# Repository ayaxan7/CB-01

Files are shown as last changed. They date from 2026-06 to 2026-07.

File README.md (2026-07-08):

# NeonCore

<p align="center">
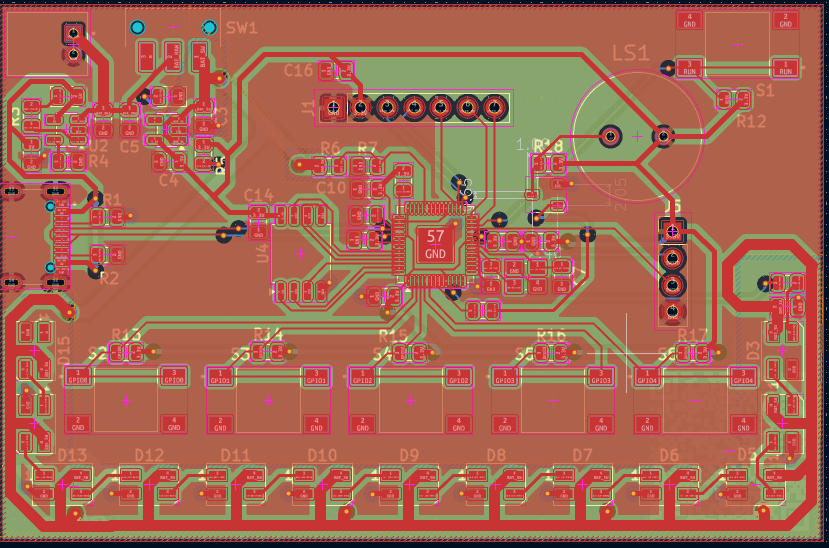
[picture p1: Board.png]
  
</p>

## RP2040 Cyberpunk Development Badge

NeonCore is a cyberpunk-inspired electronic badge built around the RP2040 microcontroller. The project combines embedded hardware with custom PCB artwork, resulting in a compact development badge that is both functional and visually distinctive.

Designed entirely in KiCad, the board includes USB Type-C connectivity, Li-Po battery support with onboard charging, RGB lighting, OLED display support, external QSPI flash memory, and onboard power management. The goal was to create a portable embedded platform that could later be extended with custom firmware and interactive applications.

---

## Features

- RP2040 Dual-Core Microcontroller
- USB Type-C Connectivity
- 3.7V Li-Po Battery Support
- MCP73831 Battery Charging Circuit
- ME6211 3.3V Voltage Regulator
- 16 × SK6812 Mini RGB LEDs
- 1.3" OLED Display Support
- External QSPI Flash Memory
- Onboard Power Switch
- Custom Cyberpunk PCB Artwork

---
## Project Status

- Schematic Completed
- PCB Layout Completed
- Design Rule Check (DRC) Passed
- Gerber Files Generated
- Ready for Fabrication

---

## Tools Used

- KiCad
- Git
- GitHub

---

<p align="center">
Designed and developed using KiCad.
</p>

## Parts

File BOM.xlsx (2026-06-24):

Qty | Value | Footprint | MANUFACTURER | MANUFACTURER PART NUMBER
1 | ABM8G-12.000MHZ-18-D2Y-T | MyLibrary:XTAL_ABM8G-12.000MHZ-18-D2Y-T | Abracon LLC | ABM8G-12.000MHZ-18-D2Y-T
13 | SK6812MINI | LED_SMD:LED_SK6812MINI_PLCC4_3.5x3.5mm_P1.75mm | Adafruit Industries LLC | 2659
3 | 1K | Resistor_SMD:R_0805_2012Metric | Stackpole Electronics Inc | RMCF0805FT1K00
1 | 5K | Resistor_SMD:R_0805_2012Metric | Bourns Inc. | CRT0805-BY-5001EAS
1 | SW_SPDT | MyLibrary:SW_JS102011SAQN | C&K | JS102011SAQN
6 | TS04-66-70-BK-160-SMT | MyLibrary:SW_TS04-66-70-BK-160-SMT | CUI Devices | TS04-66-70-BK-160-SMT
1 | NPN | MyLibrary:TRANS_MMBT3904 | Diotec Semiconductor | MMBT3904
1 | TYPE-C-31-M-12 | MyLibrary:HRO_TYPE-C-31-M-12 | HRO Electronics Co., Ltd. | TYPE-C-31-M-12
1 | Conn_01x02_Socket | MyLibrary:JST_S2B-PH-K-S_LF__SN_ | JST Sales America Inc. | S2B-PH-K-S
2 | LED | LED_SMD:LED_0805_2012Metric | Lite-On Inc. | LTST-C171KGKT
1 | MCP73831-2-OT | Package_TO_SOT_SMD:SOT-23-5 | Microchip Technology | MCP73831T-2ACI/OT
1 | ME6211C33M5 | Package_TO_SOT_SMD:SOT-23-5 | MICRONE | ME6211C33M5G-N
1 | 100uF | Capacitor_SMD:C_0805_2012Metric | Murata Electronics | GRM21BR60G107ME11K
1 | RP2040 | Package_DFN_QFN:QFN-56-1EP_7x7mm_P0.4mm_EP3.2x3.2mm | Raspberry Pi | RP2040
4 | 4.7uF | Capacitor_SMD:C_0805_2012Metric | Samsung Electro-Mechanics | CL21A475KAQNNNE
2 | 10uF | Capacitor_SMD:C_0805_2012Metric | Samsung Electro-Mechanics | CL21A106KQFNNNE
6 | 100nF | Capacitor_SMD:C_0805_2012Metric | Samsung Electro-Mechanics | CL21B104KBCNNNC
1 | 1uF | Capacitor_SMD:C_0805_2012Metric | Samsung Electro-Mechanics | CL21B105KAFNNNE
1 | PS1240P02BT | MyLibrary:XDCR_PS1240P02BT | TDK | PS1240P02BT
1 | 470 | Resistor_SMD:R_0805_2012Metric | TE Connectivity Passive Product | CRGCQ0805J470R
1 | 200 | Resistor_SMD:R_0805_2012Metric | Vishay Dale | CRCW0805200RFKEA
1 | W25Q32JVSS | Package_SO:SOIC-8_5.3x5.3mm_P1.27mm | Winbond Electronics | W25Q32JVSSIM
1 | Conn_01x07_Pin | Connector_PinHeader_2.54mm:PinHeader_1x07_P2.54mm_Vertical | Würth Elektronik | 61300711121
1 | Conn_01x04_Socket | Connector_PinHeader_2.54mm:PinHeader_1x04_P2.54mm_Vertical | Würth Elektronik | 61300411121
2 | 18pF | Capacitor_SMD:C_0805_2012Metric | YAGEO | CC0805JRNPO9BN180
1 | 5.1k | Resistor_SMD:R_0805_2012Metric | YAGEO | RC0805JR-075K1L
1 | 5.1K | Resistor_SMD:R_0805_2012Metric | YAGEO | RC0805JR-075K1L
2 | 100K | Resistor_SMD:R_0805_2012Metric | YAGEO | RC0805FR-07100KL
1 | 330 | Resistor_SMD:R_0805_2012Metric | YAGEO | RC0805FR-07330RL
6 | 10K | Resistor_SMD:R_0805_2012Metric | YAGEO | RC0805FR-0710KL

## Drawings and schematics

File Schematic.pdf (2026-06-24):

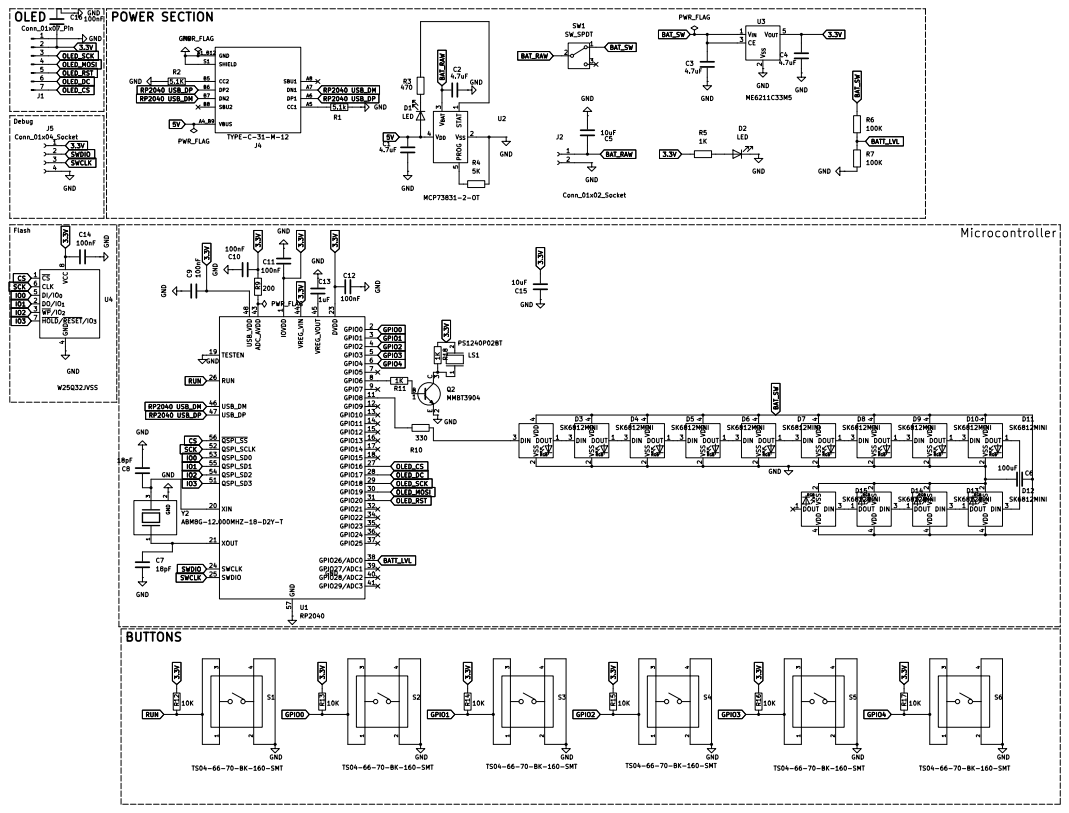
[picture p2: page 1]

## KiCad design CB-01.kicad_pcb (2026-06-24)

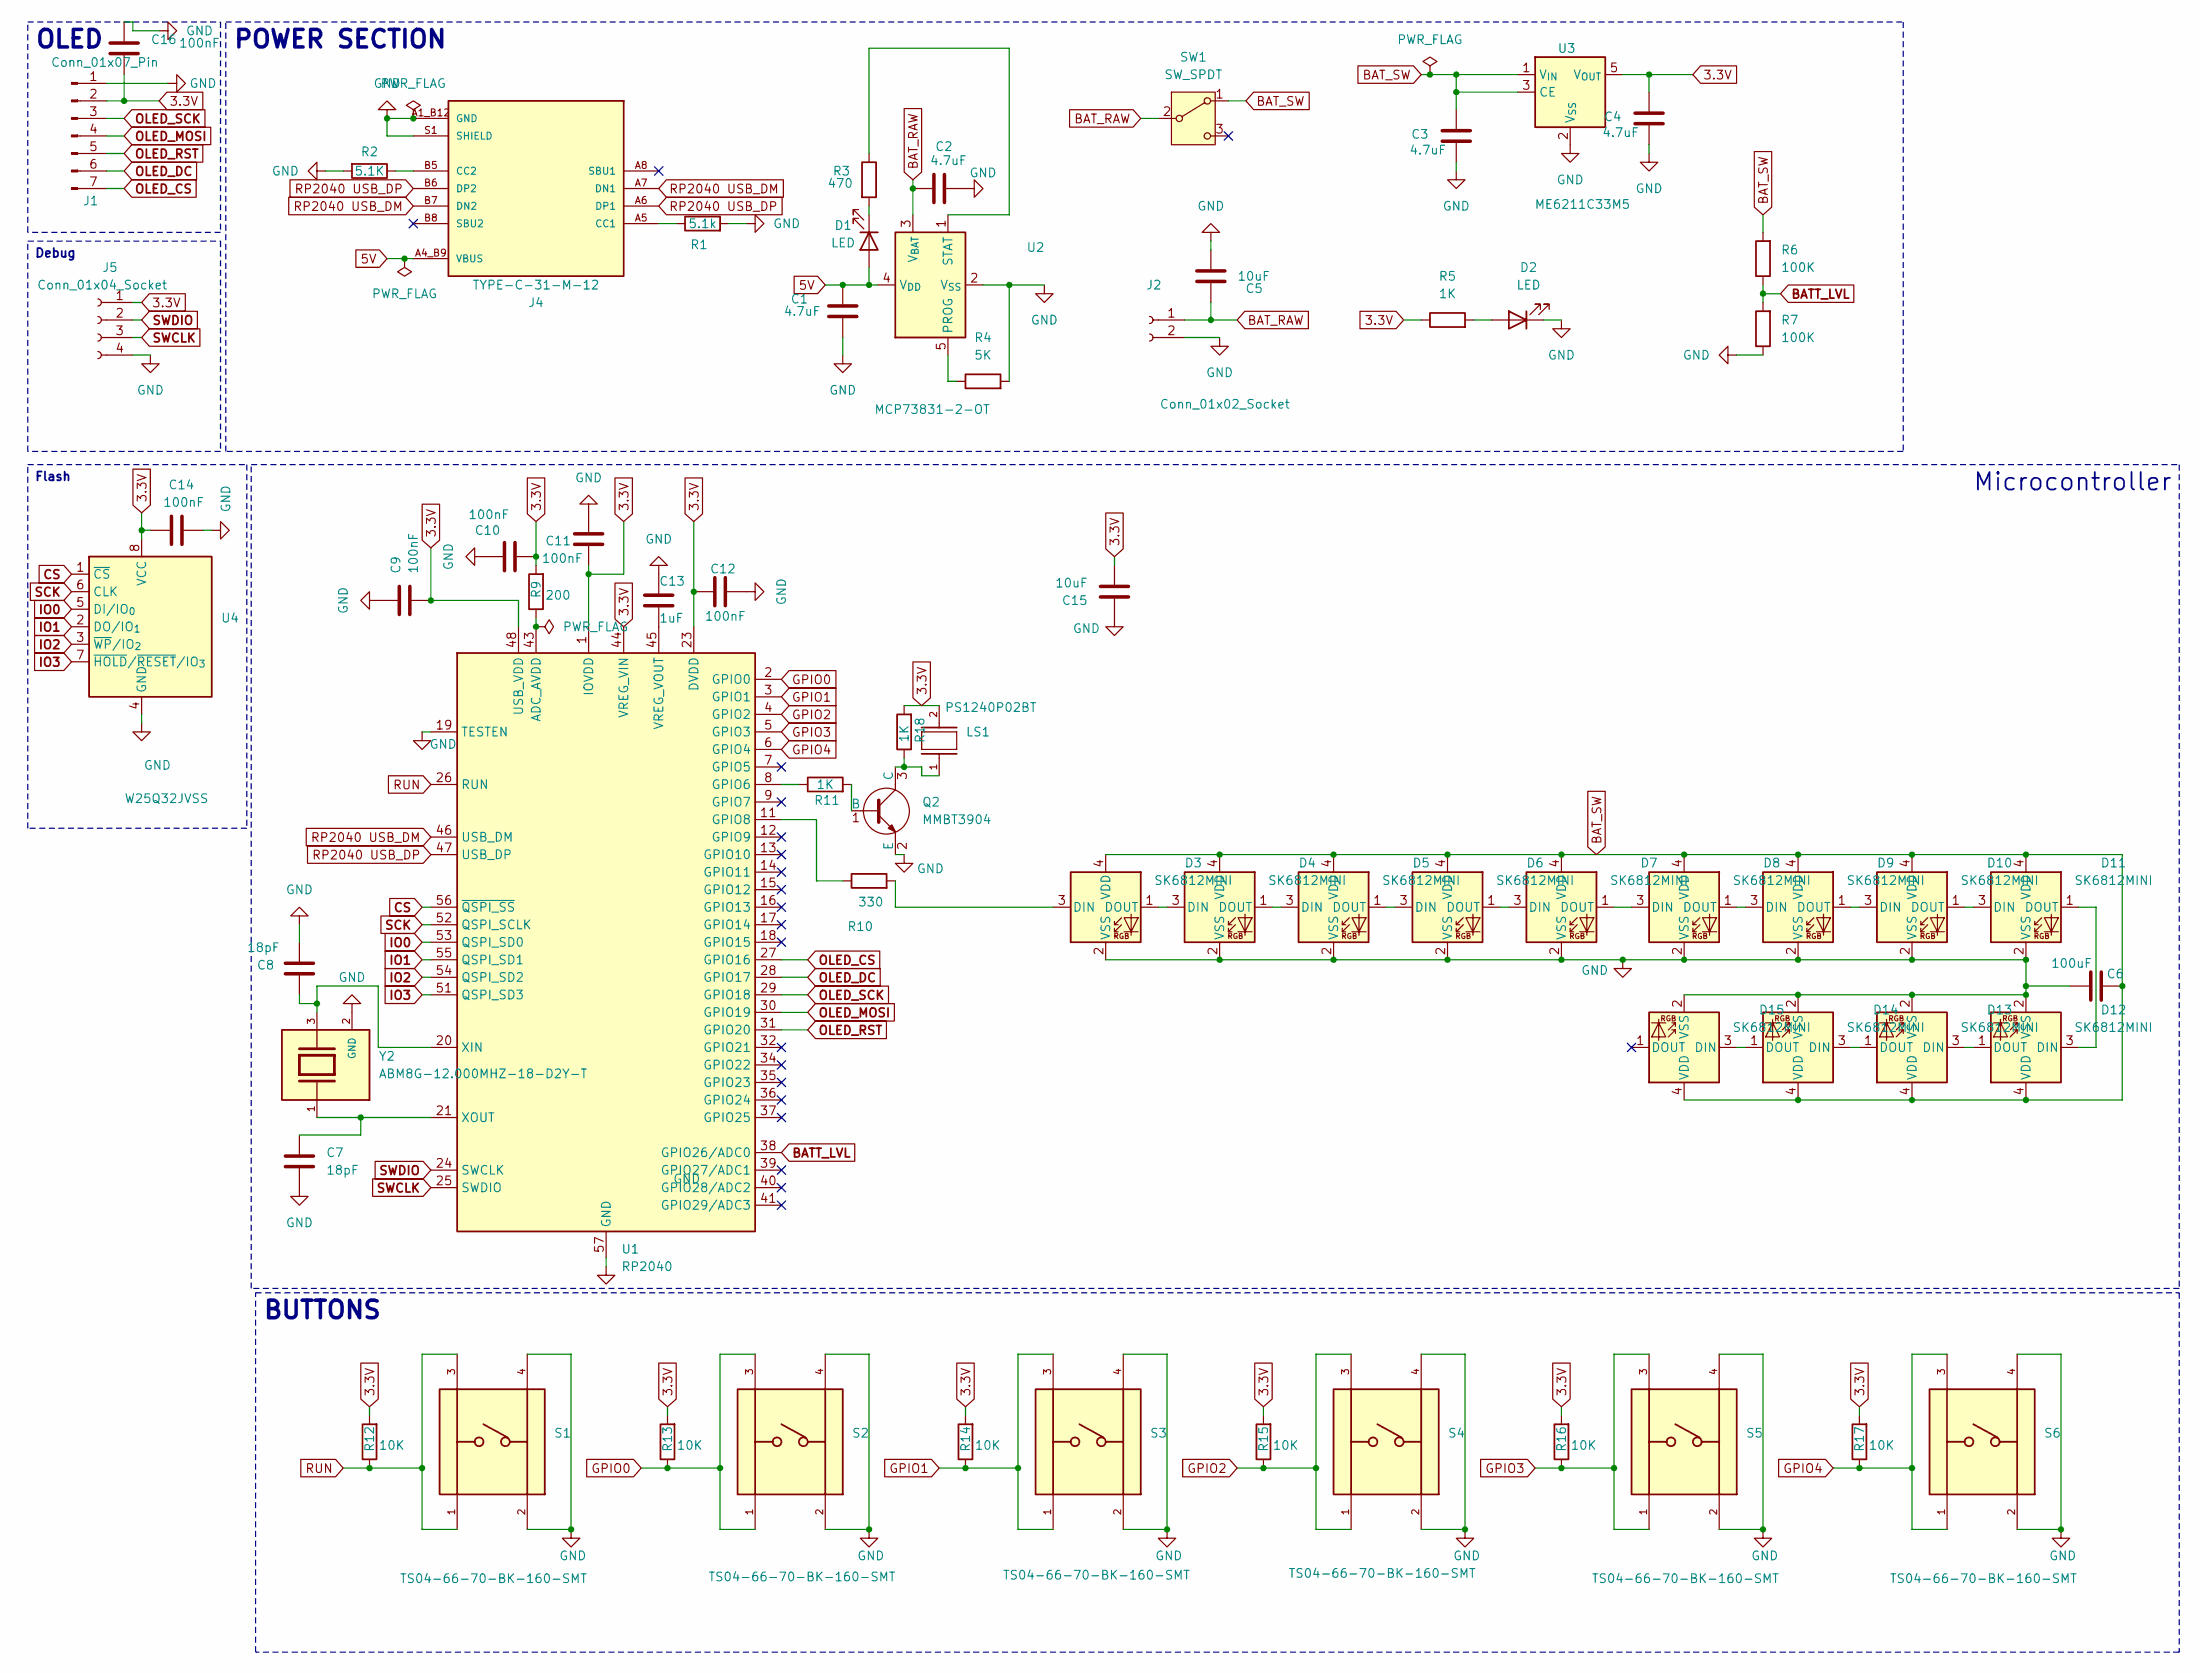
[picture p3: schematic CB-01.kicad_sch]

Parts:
C1, C2, C3, C4: 4.7uF; C_0805_2012Metric; MANUFACTURER PART NUMBER CL21A475KAQNNNE
C5, C15: 10uF; C_0805_2012Metric; MANUFACTURER PART NUMBER CL21A106KQFNNNE
C6: 100uF; C_0805_2012Metric; MANUFACTURER PART NUMBER GRM21BR60G107ME11K
C7, C8: 18pF; C_0805_2012Metric; MANUFACTURER PART NUMBER CC0805JRNPO9BN180
C9, C10, C11, C12, C14, C16: 100nF; C_0805_2012Metric; MANUFACTURER PART NUMBER CL21B104KBCNNNC
C13: 1uF; C_0805_2012Metric; MANUFACTURER PART NUMBER CL21B105KAFNNNE
D1, D2: LED; LED_0805_2012Metric; MANUFACTURER PART NUMBER LTST-C171KGKT
D3, D4, D5, D6, D7, D8, D9, D10, D11, D12, D13, D14, D15: SK6812MINI; LED_SK6812MINI_PLCC4_3.5x3.5mm_P1.75mm; MANUFACTURER PART NUMBER 2659
J1: Conn_01x07_Pin; PinHeader_1x07_P2.54mm_Vertical; MANUFACTURER PART NUMBER 61300711121
J2: Conn_01x02_Socket; JST_S2B-PH-K-S_LF__SN_; MANUFACTURER PART NUMBER S2B-PH-K-S
J4: TYPE-C-31-M-12; HRO_TYPE-C-31-M-12; PARTREV 2020.12.08
J5: Conn_01x04_Socket; PinHeader_1x04_P2.54mm_Vertical; MANUFACTURER PART NUMBER 61300411121
LS1: PS1240P02BT; XDCR_PS1240P02BT; MANUFACTURER PART NUMBER PS1240P02BT
Q2: MMBT3904; P200_SOT-23
R1: 5.1k; R_0805_2012Metric; MANUFACTURER PART NUMBER RC0805JR-075K1L
R2: 5.1K; R_0805_2012Metric; MANUFACTURER PART NUMBER RC0805JR-075K1L
R3: 470; R_0805_2012Metric; MANUFACTURER PART NUMBER CRGCQ0805J470R
R4: 5K; R_0805_2012Metric; MANUFACTURER PART NUMBER CRT0805-BY-5001EAS
R5, R11, R18: 1K; R_0805_2012Metric; MANUFACTURER PART NUMBER RES 1K OHM 1% 1/8W 0805
R6, R7: 100K; R_0805_2012Metric; MANUFACTURER PART NUMBER RC0805FR-07100KL
R9: 200; R_0805_2012Metric; MANUFACTURER PART NUMBER CRCW0805200RFKEA
R10: 330; R_0805_2012Metric; MANUFACTURER PART NUMBER RC0805FR-07330RL
R12, R13, R14, R15, R16, R17: 10K; R_0805_2012Metric; MANUFACTURER PART NUMBER RC0805FR-0710KL
S1, S2, S3, S4, S5, S6: TS04-66-70-BK-160-SMT; SW_TS04-66-70-BK-160-SMT; PARTREV 1.0
SW1: SW_SPDT; SW_JS102011SAQN; MANUFACTURER PART NUMBER JS102011SAQN
U1: RP2040; QFN-56-1EP_7x7mm_P0.4mm_EP3.2x3.2mm; MANUFACTURER PART NUMBER RP2040
U2: MCP73831-2-OT; SOT-23-5; MANUFACTURER PART NUMBER MCP73831T-2ACI/OT
U3: ME6211C33M5; SOT-23-5; MANUFACTURER PART NUMBER ME6211C33M5G-N
U4: W25Q32JVSS; SOIC-8_5.3x5.3mm_P1.27mm; MANUFACTURER PART NUMBER W25Q32JVSSIM
Y2: ABM8G-12.000MHZ-18-D2Y-T; XTAL_ABM8G-12.000MHZ-18-D2Y-T; PARTREV 08.13.15

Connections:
3.3V: C4.1, C9.2, C10.2, C11.2, C12.2, C14.2, C15.2, C16.2, J1.2, J5.1, LS1.2, R5.1, R9.2, R12.2, R13.2, R14.2, R15.2, R16.2, R17.2, R18.2, U1.1 (IOVDD), U1.10 (IOVDD), U1.22 (IOVDD), U1.23 (DVDD), U1.33 (IOVDD), U1.42 (IOVDD), U1.44 (VREG_VIN), U1.48 (USB_VDD), U1.49 (IOVDD), U1.50 (DVDD), U3.5 (V_{OUT}), U4.8 (VCC)
5V: C1.1, D1.2 (A), J4.A4_B9 (VBUS), J4.B4_A9 (VBUS), U2.4 (V_{DD})
BATT_LVL: R6.1, R7.2, U1.38 (GPIO26/ADC0)
BAT_RAW: C2.1, C5.1, J2.1, SW1.2 (B), U2.3 (V_{BAT})
BAT_SW: C3.1, C6.2, D3.4 (VDD), D4.4 (VDD), D5.4 (VDD), D6.4 (VDD), D7.4 (VDD), D8.4 (VDD), D9.4 (VDD), D10.4 (VDD), D11.4 (VDD), D12.4 (VDD), D13.4 (VDD), D14.4 (VDD), D15.4 (VDD), R6.2, SW1.1 (A), U3.1 (V_{IN}), U3.3 (CE)
CS: U1.56 (~QSPI_SS), U4.1 (~CS)
GND: C1.2, C2.2, C3.2, C4.2, C5.2, C6.1, C7.2, C8.2, C9.1, C10.1, C11.1, C12.1, C13.1, C14.1, C15.1, C16.1, D2.1 (K), D3.2 (VSS), D4.2 (VSS), D5.2 (VSS), D6.2 (VSS), D7.2 (VSS), D8.2 (VSS), D9.2 (VSS), D10.2 (VSS), D11.2 (VSS), D12.2 (VSS), D13.2 (VSS), D14.2 (VSS), D15.2 (VSS), J1.1, J2.2, J4.A1_B12 (GND), J4.B1_A12 (GND), J4.S1 (SHIELD), J4.S2 (SHIELD), J4.S3 (SHIELD), J4.S4 (SHIELD), J5.4, Q2.2 (E), R1.2, R2.2, R4.2, R7.1, S1.2, S1.4, S2.2, S2.4, S3.2, S3.4, S4.2, S4.4, S5.2, S5.4, S6.2, S6.4, U1.19 (TESTEN), U1.57 (GND), U2.2 (V_{SS}), U3.2 (V_{SS}), U4.4 (GND), Y2.2 (GND), Y2.4 (GND)
GPIO0: R13.1, S2.1, S2.3, U1.2 (GPIO0)
GPIO1: R14.1, S3.1, S3.3, U1.3 (GPIO1)
GPIO2: R15.1, S4.1, S4.3, U1.4 (GPIO2)
GPIO3: R16.1, S5.1, S5.3, U1.5 (GPIO3)
GPIO4: R17.1, S6.1, S6.3, U1.6 (GPIO4)
IO0: U1.53 (QSPI_SD0), U4.5 (DI/IO_{0})
IO1: U1.55 (QSPI_SD1), U4.2 (DO/IO_{1})
IO2: U1.54 (QSPI_SD2), U4.3 (~WP/IO_{2})
IO3: U1.51 (QSPI_SD3), U4.7 (~HOLD/~RESET/IO_{3})
unnamed: D1.1 (K), R3.2
unnamed: D2.2 (A), R5.2
unnamed: D3.3 (DIN), R10.2
unnamed: D3.1 (DOUT), D4.3 (DIN)
unnamed: D4.1 (DOUT), D5.3 (DIN)
unnamed: D5.1 (DOUT), D6.3 (DIN)
unnamed: D6.1 (DOUT), D7.3 (DIN)
unnamed: D7.1 (DOUT), D8.3 (DIN)
unnamed: D8.1 (DOUT), D9.3 (DIN)
unnamed: D9.1 (DOUT), D10.3 (DIN)
unnamed: D10.1 (DOUT), D11.3 (DIN)
unnamed: D11.1 (DOUT), D12.3 (DIN)
unnamed: D12.1 (DOUT), D13.3 (DIN)
unnamed: D13.1 (DOUT), D14.3 (DIN)
unnamed: D14.1 (DOUT), D15.3 (DIN)
unnamed: J4.A5 (CC1), R1.1
unnamed: J4.B5 (CC2), R2.1
unnamed: Q2.1 (B), R11.2
unnamed: LS1.1, Q2.3 (C), R18.1
unnamed: R9.1, U1.43 (ADC_AVDD)
unnamed: R11.1, U1.8 (GPIO6)
unnamed: R10.1, U1.11 (GPIO8)
unnamed: C13.2, U1.45 (VREG_VOUT)
unnamed: C8.1, U1.20 (XIN), Y2.3
unnamed: C7.1, U1.21 (XOUT), Y2.1
unnamed: R4.1, U2.5 (PROG)
unnamed: R3.1, U2.1 (STAT)
OLED_CS: J1.7, U1.27 (GPIO16)
OLED_DC: J1.6, U1.28 (GPIO17)
OLED_MOSI: J1.4, U1.30 (GPIO19)
OLED_RST: J1.5, U1.31 (GPIO20)
OLED_SCK: J1.3, U1.29 (GPIO18)
RP2040 USB_DM: J4.A7 (DN1), J4.B7 (DN2), U1.46 (USB_DM)
RP2040 USB_DP: J4.A6 (DP1), J4.B6 (DP2), U1.47 (USB_DP)
RUN: R12.1, S1.1, S1.3, U1.26 (RUN)
SCK: U1.52 (QSPI_SCLK), U4.6 (CLK)
SWCLK: J5.3, U1.25 (SWDIO)
SWDIO: J5.2, U1.24 (SWCLK)

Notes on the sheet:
BUTTONS
Flash
Microcontroller
Debug
OLED
POWER SECTION

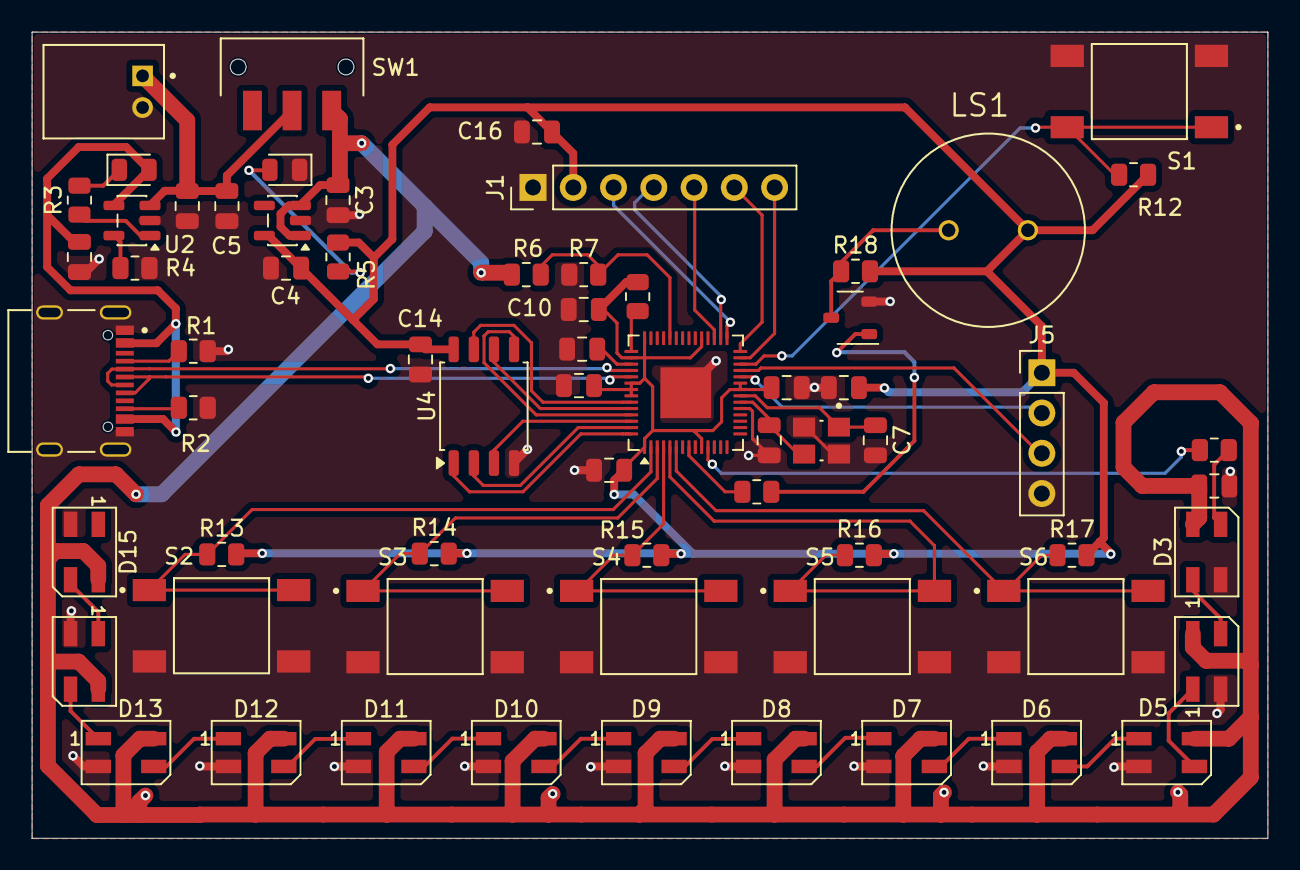
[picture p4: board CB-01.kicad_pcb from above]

Board: 4 copper layers, 78.0 x 50.9 mm, 66 parts (0 on the bottom side), 54 nets.

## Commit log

2026-06-24 first kick
    [BOM.xlsx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]
2026-06-24 updated files
    [CB-01.kicad_pcb, CB-01.kicad_sch]
